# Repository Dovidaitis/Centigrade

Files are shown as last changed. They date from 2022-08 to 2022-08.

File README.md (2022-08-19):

This system protytype was build during the COVID-19 pandemic

# Hardware of the project

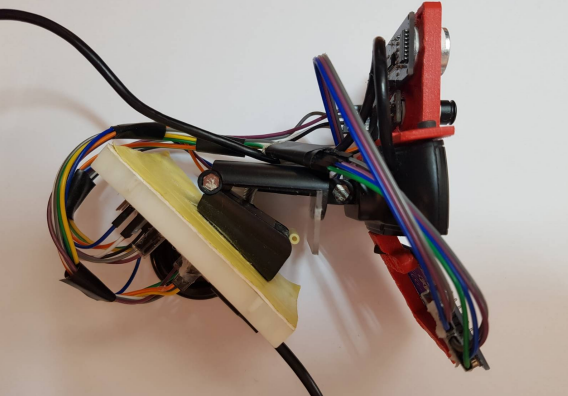
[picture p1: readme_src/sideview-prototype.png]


# Real time system prototype testing

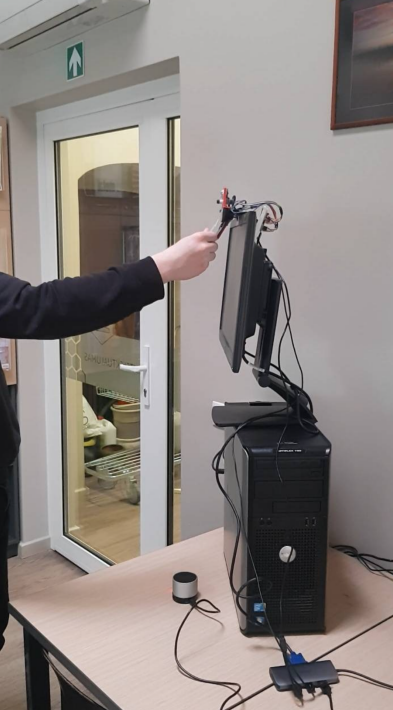
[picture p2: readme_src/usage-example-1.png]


# Guide how to build this project
1. Create virtual environment ```python -m venv env```
2. Run virtual environment activation script ``` /env/Scripts/activate.bat```
3. Run ```setup.py``` to install required dependencies
4. 3D print required parts. (.stl files can be found at ```03_centigrade_CAD``` directory)

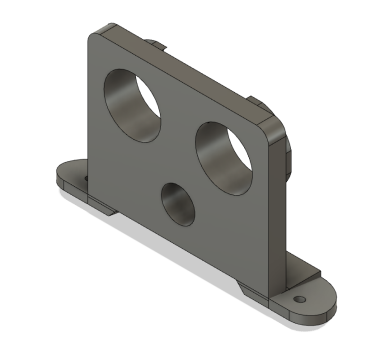
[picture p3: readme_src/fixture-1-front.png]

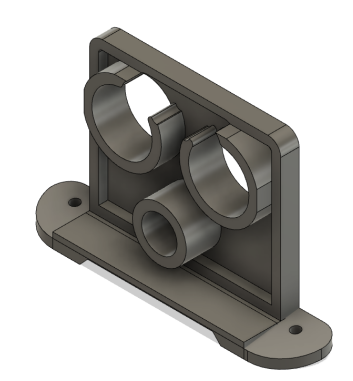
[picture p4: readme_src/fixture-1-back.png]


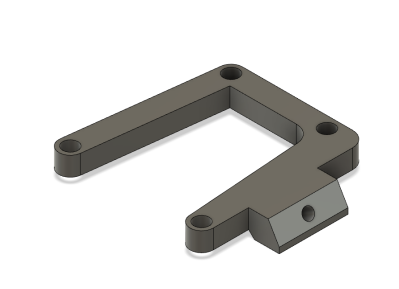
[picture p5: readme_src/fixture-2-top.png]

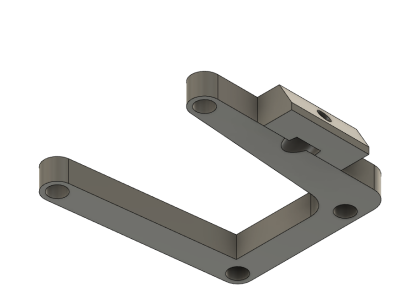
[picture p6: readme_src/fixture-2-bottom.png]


__Note that the fixtures are adapted to this no-brand webcam from aliexpress:__

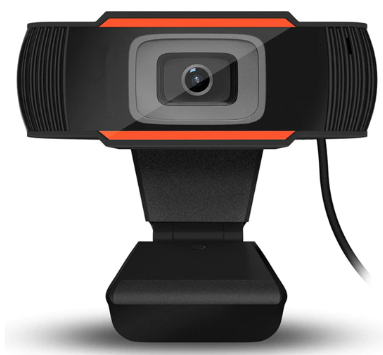
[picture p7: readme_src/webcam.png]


6.  Using the diagram below, make specified connections
```
Pinout for RFID RC522 
3V3 - 3.3V/VCC
GND - GND
 D9 - RST(RESET)
D10 - SDA(SS)
D11 - MOSI
D12 - MISO
D13 - SCK

Pinout for MLX90614 DCI (Infrared Temperature Sensor)
3V3 - VIN/VCC
GND - GND
A4 - SDA
A5 - SCL

Pinout for HC-SR04 (Ultrasonic)
Gnd - GND
Echo - D2
Trig - D3
Vcc - 5V
```

7. Upload ```main.ino``` file to ```Arduino Nano```
8. Connect ```Arduino``` and USB webcam to your local machine and run ```main.py```

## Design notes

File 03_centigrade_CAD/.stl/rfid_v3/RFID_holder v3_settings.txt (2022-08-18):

Application version: 2.16.2.0
Estimated print time: 0h 45m
Material usage: 2.51m (8g)
Printer: Zortrax M200
Profile: Last settings
Support type: Automatic
Support: 20°
Material: PLA-based filament
Nozzle diameter: 0.4 mm
Layer: 0.14 mm
Quality: Default
Infill: 50%
Fan speed: 75%
Seam: Normal
Outer contours: 0.00
Holes: 0.00
Surface layers Top: 6
Surface layers Bottom: 3
Support Lite: No
Smart bridges: Yes
Support offset: No
First layer Density: 100%
First layer Print speed: 100%
First layer Flow ratio: 100%
First layer gap: 0.39 mm
Raft Enabled: Yes
Raft layers: 7
Platform-raft gap: 0.32 mm
Raft Density: 80%
Raft Print speed: 100%
Raft Flow ratio: 100%
Print speed: +0%
Extruder flow ratio: +0%
Top layer infill (%): 100
Bottom layer infill (%): 100
Extrusion temp.: 269
Platform temp.: 30
Retraction speed: 36
Retraction distance: 1.2
Support Density: 4.00 mm
Gap XY: 0.68

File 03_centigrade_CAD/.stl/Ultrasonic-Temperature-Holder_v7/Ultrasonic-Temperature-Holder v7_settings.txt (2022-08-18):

Application version: 2.16.2.0
Estimated print time: 2h 39m
Material usage: 5.16m (17g)
Printer: Zortrax M200
Profile: Last settings
Support type: Automatic
Support: 20°
Material: PLA-based filament
Nozzle diameter: 0.4 mm
Layer: 0.09 mm
Quality: Default
Infill: 30%
Fan speed: 70%
Seam: Normal
Outer contours: 0.00
Holes: 0.00
Surface layers Top: 9
Surface layers Bottom: 3
Support Lite: No
Smart bridges: Yes
Support offset: No
First layer Density: 100%
First layer Print speed: 100%
First layer Flow ratio: 100%
First layer gap: 0.37 mm
Raft Enabled: Yes
Raft layers: 7
Platform-raft gap: 0.32 mm
Raft Density: 100%
Raft Print speed: 100%
Raft Flow ratio: 100%
Print speed: +0%
Extruder flow ratio: +0%
Top layer infill (%): 100
Bottom layer infill (%): 100
Extrusion temp.: 260
Platform temp.: 30
Retraction speed: 36
Retraction distance: 1.2
Support Density: 4.00 mm
Gap XY: 0.68

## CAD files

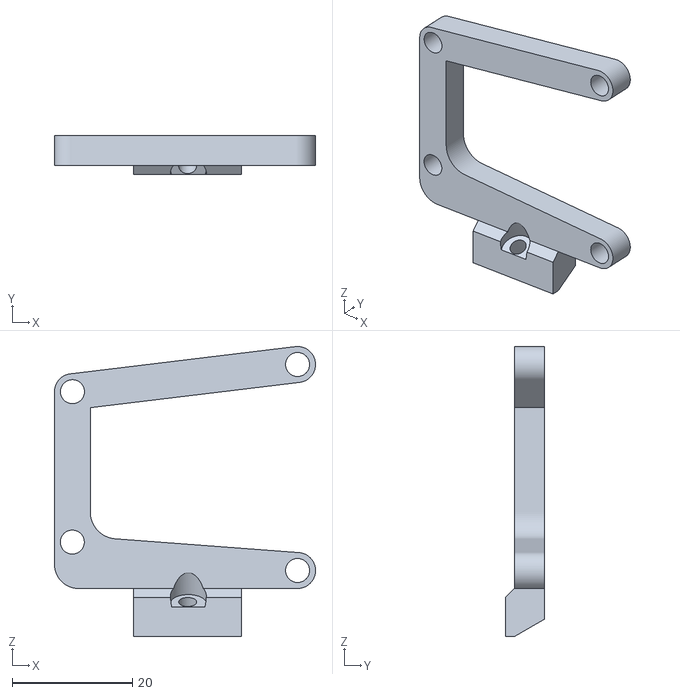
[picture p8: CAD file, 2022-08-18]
03_centigrade_CAD/.stl/rfid_v3/RFID_holder v3.stl
43.5 x 6.50 x 48.3

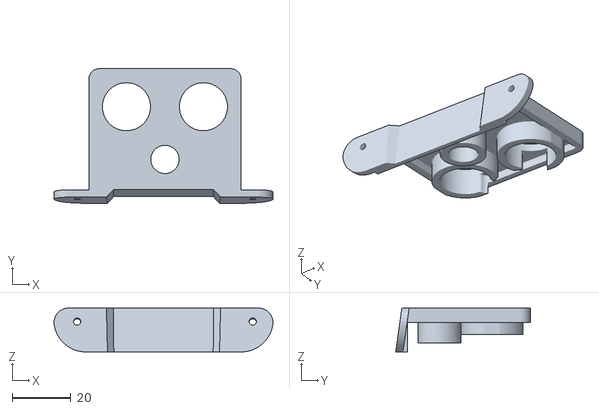
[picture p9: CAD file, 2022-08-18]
03_centigrade_CAD/.stl/Ultrasonic-Temperature-Holder_v7/Ultrasonic-Temperature-Holder v7.stl
74.8 x 46.0 x 15.0

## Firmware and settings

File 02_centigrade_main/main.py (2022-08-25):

from cgitb import text
from serial_communication import SerialCom
from user import User
from computer_vision.face_detection import FaceDetection
from apis.gmail_api import GmailService
from apis.sheets_api import *
import time
from playsound import playsound
import threading
import socket
import os




STATION_NAME = socket.gethostname()

print("main.py running")
print("check...")

def main():

    convert = lambda value: True if "TRUE" else False
    sound_not_playing = True
    
    log = SheetsEntry()
    settings = log.new_settings()

    fd = FaceDetection()
    fd.DISPLAY = convert(settings['display'])
    fd.MIN_FACE_SIZE = settings['min_face_size'] # 275
    LOGS = True
    SAVE_IMG = convert(settings['save_img'])
    CRITICAL_TEMP = settings['critical_temp']

    print(f"selected CRITICAL_TEMP is: {CRITICAL_TEMP} asdf")
    time.sleep(5)




    if LOGS:
        gmail_service = GmailService()
        gmail_service.supervisors_emails = settings['supervisor_emails'].split(';')
        log.open_log_sheet()

    last_user_id = ""



    arduino = SerialCom('115200')
    print(arduino.connection_established, arduino.serial_baudrate, arduino.com_port, sep='\n')

    if arduino.connection_established:

        db = Cache("db")
        cached_log = False
        cached_email = False
        sound_counter = 0

        while True:
            sound_counter += 1

            if sound_counter == 50:
                sound_counter = 1
                sound_not_playing = True

            text_to_display = ""
            frame = fd.mirror_img(fd.create_frame())
            
            grey_frame = fd.create_grey_frame(frame)

            faces_cords = fd.get_faces_cords(grey_frame)
            face_size = fd.find_face_target_size(faces_cords)

            user_data = arduino.receive_serial_data()
            time_received = log.timestamp()

            print(f"{user_data}")
            current_user = User(user_data)
            

            if face_size < fd.MIN_FACE_SIZE and current_user.distance > 40:
                text_to_display = f" {current_user.distance}cm "
                if current_user.rfid == "00000000":
                    text_to_display += " Scan RFID"
            else:
                if current_user.rfid == "00000000":
                    text_to_display += " Scan your RFID card"
                    text_to_display += f" Temp: {current_user.temperature}. "
                    if sound_not_playing:
                        threading.Thread(target=playsound, args=("audio_instructions/scan_rfid.mp3",)).start()
                        sound_not_playing = False
                else:
                    if float(current_user.temperature) > 30:

                        text_to_display = "Normal temperature, go on."
                        if sound_not_playing:
                            threading.Thread(target=playsound, args=("audio_instructions/normal_temp.mp3",))
                            sound_not_playing = False

                        if current_user.rfid != last_user_id:
                            if LOGS:
                                log_data = log.create_data_row(time_received, 
                                                                STATION_NAME,
                                                                current_user.rfid,
                                                                current_user.temperature)
                                try:
                                    threading.Thread(log.push_temp, args=(log_data,)).start()
                                except Exception as e:
                                    db.save_log(log_data)
                                    cached_log = True
                                    DebugLogs().debug_log(f"log.push_temp() failed", e)
                            if SAVE_IMG:
                                fd.save_img(frame)
                            last_user_id = current_user.rfid
        
                    if current_user.temperature > CRITICAL_TEMP:
                        text_to_display = "Recheck your temperature manually"
                        if sound_not_playing:
                            threading.Thread(target=playsound, args=("audio_instructions/recheck_temp.mp3",))
                            sound_not_playing = False
                        if LOGS:
                            report_letter = gmail_service.generate_report(f"User with id: {current_user.rfid}", 
                                                                            current_user.temperature,
                                                                            STATION_NAME)
                            try:
                                threading.Thread(target=gmail_service.report_user, args=(report_letter,)).start()
                                print("user reported")
                            except Exception as e:
                                # update local cache
                                db.save_email_notification(report_letter)
                                cached_email = True
                                DebugLogs().debug_log(f"report_user() in main() failed with report letter:\n {report_letter}", e)

            if fd.should_break():
                break
            try:
                fd.display_cam(faces_cords, frame, text_to_display)
            except Exception as e:
                DebugLogs().debug_log("display_cam() failed in main()", e)

            if cached_log:
                try:
                    db.reupload_log(log)
                    cached_log = False
                except Exception as e:
                    DebugLogs().debug_log("db.reupload_log() failed", e)
            
            if cached_email:
                try:
                    db.resend_emails(gmail_service)
                    cached_email = False
                except Exception as e:
                    DebugLogs().debug_log("db.resend_emails() failed", e)

    else:
        print("arduino connection is not established")
        if LOGS:
            gmail_service.send_email("Arduino connection failed...", "centigrade@kjg.lt", "Arduino was not connected")



if __name__ == "__main__":
    while True:
        main()
        time.sleep(5)

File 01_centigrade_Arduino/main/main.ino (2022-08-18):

// Arduino NANO pinout
// 
// ---RFID RC522---
// 3V3 - 3.3V/VCC
// GND - GND
// D9  - RST(RESET)
// D10 - SDA(SS)
// D11 - MOSI
// D12 - MISO
// D13 - SCK 
// ----------------

// --MLX90614 DCI--
// 3V3 - VIN/VCC
// GND - GND
// A4  - SDA
// A5  - SCL
// ----------------

// ----HC-SR04----
// Gnd - GND
// Echo - D2
// Trig - D3
// Vcc - 5V
// ---------------

// for MLX
#include <Wire.h>
#include <Adafruit_MLX90614.h>

// for RFID
#include <SPI.h>
#include <MFRC522.h>

#define echoPin 2 // attach pin D2 Arduino to pin Echo of HC-SR04
#define trigPin 3 //attach pin D3 Arduino to pin Trig of HC-SR04

#define SS_PIN 10
#define RST_PIN 9
MFRC522 mfrc522(SS_PIN, RST_PIN);   // Create MFRC522 instance. (RFID)

// variables for echo
long duration; 
int distance; 

// MLX object
Adafruit_MLX90614 mlx = Adafruit_MLX90614();

double temp_amb;
double temp_obj;
double OUTLIER_TEMP_LOW = 30.0;
double OTLIER_TEMP_HIGH = 42.0;

int wait_miliseconds = 50;

String G_UID = "00000000";
String P_UID;

void setup() {
  Serial.begin(115200); 
  Serial.println("000");
  
  pinMode(trigPin, OUTPUT); // Sets the trigPin as an OUTPUT
  pinMode(echoPin, INPUT); // Sets the echoPin as an INPUT

  mlx.begin(); //Initialize MLX90614

  SPI.begin();
  mfrc522.PCD_Init(); // init RFID
}

int loop_count = 0;

void loop() {  
  if (loop_count == 100){
    G_UID = "00000000";
    loop_count = 0;
  }
  read_uid();
  
  String data = "";
  data.concat(String(measure_distance()));
  data.concat("-");
  data.concat(String(get_avg_temp()));
  data.concat("-");
  data.concat(G_UID);
  Serial.println(data);
  
  delay(wait_miliseconds);
  loop_count++;
}
